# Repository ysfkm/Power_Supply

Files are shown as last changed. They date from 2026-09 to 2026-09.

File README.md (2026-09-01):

# Power Supply

## Summary
- Custom linear-regulator power supply boards providing multiple regulated rails from a raw input voltage.
- **v0.1:** 24V input board with four fixed regulators (15V, 12V, 5V, 3V3) plus two variable outputs via jumpers and a buck converter; four-layer 157.5mm x 100mm PCB.
- **v1.1:** Revised ±15V input board delivering +12V and -5V, entirely from linear regulators (12V now derived from 15V instead of 24V, plus a new -5V rail); same 4-layer 157.5mm x 100mm PCB footprint.

## v0.1

### Specs
- **Input:** +24V
- **Output:** +15V, +12V, +5V, +3V3, two variable voltage outputs
- **Description:** one output for each voltage value and two variable outputs via jumpers. Uses four regulators and one buck converter.
- **PCB:** 157.5mm x 100mm / 4 Layer

### 15V Voltage Regulator
- **Input:** 24V, GNDA
- **Output:** 15V, GNDA
- **Maximum Output Current:** 1A
- **Thermal Resistance:** 44.8°C/W

### 12V Voltage Regulator
- **Input:** 24V, GNDA
- **Output:** 12V, GNDA
- **Maximum Output Current:** 1A
- **Thermal Resistance:** 44.8°C/W

### 5V Voltage Regulator
- **Input:** 24V, GNDA
- **Output:** 5V, GNDA
- **Maximum Output Current:** 1.2A
- **9V Buck Converter Thermal Resistance:** 50°C/W
- **5V Linear Regulator Thermal Resistance:** 44.8°C/W

### 3V3 Voltage Regulator
- **Input:** 9V, GNDA
- **Output:** 3V3, GNDA
- **Maximum Output Current:** 5A
- **Thermal Resistance:** 44.8°C/W

### Design Process
- Thermal vias for each regulator for heat dissipation
- Buck converter routed to minimize loop area of interference
- Built four voltage regulators separately, then tested out ideas on how to put together a combined power supply board
- Settled on two variable outputs and four constant outputs

## v1.1

### Specs
- **Input:** +15V, -15V, GNDA
- **Output:** +12V, -5V, GNDA
- **Description:** three output ports for each voltage value. All regulated from linear regulators
- **PCB:** 157.5mm x 100mm / 4 Layer

### 12V Voltage Regulator
- **Input:** 15V, GNDA
- **Output:** 12V, GNDA
- **Maximum Output Current:** 1.5A
- **Thermal Resistance:** 19°C/W

### -5V Voltage Regulator
- **Input:** -15V, GNDA
- **Output:** -5V, GNDA
- **Maximum Output Current:** 1A
- **Thermal Resistance:** 65°C/W

### Design Changes
- Needed -5V supply so made a new version of the board with 12V and -5V
- 12V now regulated from 15V instead of 24V, so used a different regulator

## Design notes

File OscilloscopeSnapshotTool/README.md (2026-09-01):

# Power Supply Snapshot Tool

A small tool for grabbing a one-shot snapshot from the Rigol DS1104Z Plus
oscilloscope over LAN — for documenting the ripple/noise performance, its
frequency spectrum, and the actual output level of the power supply
board's outputs. Each run saves a screenshot and the underlying waveform
data for **three** passes — AC-coupled (ripple/noise), FFT (frequency
spectrum of that ripple), and DC-coupled (actual level) — together in
their own timestamped folder, so it's always obvious which files belong
together. There's also an optional **long capture** — a much longer
(1,000,000-point) raw trace and a full-resolution FFT computed from it —
you can tick on before clicking Take Snapshot; see
[Long trace capture](#long-trace-capture) below.

Waveform data is saved as compressed NumPy `.npz` files rather than CSV
(a PI's suggestion, since the long trace in particular is unwieldy as
text) — see [Reading the .npz files in Python](#reading-the-npz-files-in-python).

## What it does

Each time you click **Take Snapshot** (or run the command-line version),
the tool:

1. Connects to the oscilloscope over LAN.
2. **AC pass**: sets CH1 to AC coupling with a fixed **10mV/div scale,
   0V offset, and 100ns/div timebase** (so ripple is clearly visible
   regardless of what was set before), turns the "Measure All" statistics
   table **off** (to give the waveform as much of the plot as possible),
   freezes the trace, and saves the waveform (`.npz`) and screenshot (PNG)
   as `..._AC.npz` / `..._AC.png`.
3. **FFT pass**: uses the scope's built-in MATH FFT feature on that same
   AC-coupled signal, first switching to a **10µs/div timebase** (the
   FFT's frequency range/resolution comes from this, not a separate
   setting - a slower timebase than AC's gives better low-frequency
   resolution for typical switching-noise frequencies) - Hanning window,
   dB units, full-screen grid, CH1's time-domain trace still shown
   alongside it, auto-scaled via `:MATH:RESet` after giving the scope a
   moment to compute a real result first - to get the frequency spectrum,
   "Measure All" also off. It then repositions **0Hz to the left edge**
   and **0dB to the vertical center** of the spectrum plot (see "FFT axis
   positioning" below) and saves `..._FFT.npz` (frequency_hz,
   magnitude_dB) / `..._FFT.png`.
4. **DC pass**: switches CH1 to DC coupling, a fixed **1ms/div timebase**
   (this pass just reads a level, so the exact timebase barely matters -
   picked a fixed, moderate value rather than depending on whatever the
   scope was last left at), and a scale/offset that frames the actual
   output level — based on the **expected DC voltage** you type in (see
   below), or a safe wide default if left blank — turns "Measure All"
   **on** (useful alongside the level readout here), then freezes the
   trace and saves `..._DC.npz` / `..._DC.png`.
5. Measures the actual DC level and reports how it compares to what you
   expected (higher/lower, and by how much).
6. Resumes live acquisition on the scope so you can keep watching between
   captures — you never need to touch Run/Stop yourself. The scope is left
   showing the **DC pass's settings** (not reverted back to AC) and
   actively running, not frozen.

The AC pass uses **fixed** scale/offset/timebase every run (rather than
trying to preserve whatever was manually set before) — this is deliberate,
since letting it drift from run to run made AC data look inconsistent
between captures for no real circuit reason. If 10mV/div or 100ns/div
isn't right for what you're seeing, change `AC_FIXED_SCALE` /
`AC_FIXED_TIMEBASE` near the top of `capture.py`. The FFT window function,
units, and timebase are similarly fixed via `FFT_WINDOW` / `FFT_UNIT` /
`FFT_FIXED_TIMEBASE`, and the DC pass's timebase via `DC_FIXED_TIMEBASE`,
in the same file.

## Expected DC voltage field

This is optional but recommended. Typing in the rail's nominal voltage
(e.g. `12`, `5`, `3.3`) before capturing:
- Sets a scale/offset that safely frames and centers that value on screen
  before switching to DC coupling.
- Gets compared against the actual measured level afterward, so you can
  immediately see if the rail is reading higher or lower than expected and
  by how much.

If left blank, the DC pass falls back to a generously wide scale so
nothing clips, at the cost of less precise framing and no comparison.

## 1. One-time setup (per computer)

If you don't already have Python:
1. Download Python 3.11+ from https://www.python.org/downloads/
2. During install, check **"Add python.exe to PATH"**.
3. Verify from a terminal: `python --version`

If you already have another Python install (e.g. from MSYS2, Anaconda, or a
Microsoft Store install) and `python --version` doesn't show the one you
just installed, use the **`py`** launcher command instead of `python` for
everything below (`py --version`, `py -m pip install ...`, `py main.py`).

Then install the dependencies (only needs doing once per computer):
```
cd "G:\Shared drives\IAMSYbElectronics\Projects\Power_Supply\OscilloscopeSnapshotTool"
pip install -r requirements.txt
```

## 2. Find the oscilloscope's IP address

On the DS1104Z Plus:
1. Press **Utility** on the front panel.
2. Go to **IO Setting** (or **System → IO**, depending on firmware).
3. Select **LAN** and confirm it shows a real IP address (not `0.0.0.0`).

Make sure the scope and your computer are on the same network.

## 3. Wiring

Probe the power supply output you're testing with the scope's **CH1**
input. The tool always captures CH1 — if you need to probe a different
channel, change the `CHANNEL` constant near the top of `capture.py`.

## 4. Taking a snapshot

There are two ways to run this: the **GUI** (recommended, no typing
commands each time) or the **command line** script.

### GUI

1. Run:
   ```
   python main.py
   ```
   The window has a fixed size, but its content scrolls (mouse wheel, or
   the scrollbar on the right) if it doesn't fully fit - e.g. on a
   smaller screen or with larger system font/DPI scaling.
2. Enter the scope's IP address and click **Test Connection** to confirm
   it's reachable (you should see its `*IDN?` response pop up).
3. Optionally, type in the rail's **expected DC voltage**.
4. Optionally, tick **Also do a long capture** if you want the much
   longer raw trace + FFT this run too — see
   [Long trace capture](#long-trace-capture) below for what that gives
   you and when you'd want it.
5. Click **Take Snapshot**. The progress bars (AC, FFT, DC, and Long
   capture if ticked) show which pass is currently running, then switch
   to "Done" once each finishes. The scope freezes briefly during each
   pass and resumes automatically afterward. If the long capture checkbox
   was left unticked, its progress bar just stays "Idle" the whole time —
   that pass is skipped entirely.
6. Once everything shows "Done", the label below shows the folder it
   saved to, plus the measured DC level (and how it compares to what you
   typed in, if anything).

Click **Take Snapshot** again for each new output/condition you want to
document — every click gets its own timestamped folder, so nothing gets
overwritten.

### Command line (alternative)

```
python capture.py <scope_ip>
```
It'll then prompt for the expected DC voltage and whether to include a
long capture too (press Enter to skip either). Same behavior as the
GUI's Take Snapshot button, just without the window — useful if you want
to script/automate captures yourself.

Either way, output lands in `Snapshots\snapshot_<timestamp>\`, containing:
- `snapshot_<timestamp>_AC.npz` / `_AC.png` — ripple/noise
- `snapshot_<timestamp>_FFT.npz` / `_FFT.png` — frequency spectrum of the ripple
- `snapshot_<timestamp>_DC.npz` / `_DC.png` — actual output level
- `longcapture_<timestamp>\` — only if the long capture was included (see
  below)

All files share the same timestamp, so they're always easy to match up.

## Long trace capture

An optional capture (a PI's suggestion) for cases where the regular
~1200-point AC/FFT passes above aren't enough — it reads back the scope's
**full internal acquisition memory** for CH1 (1,000,000 points, same
fixed AC-coupled scale/offset/timebase as the regular AC pass — this is
meant to be the same ripple signal, just with far more of the actual
acquisition read back instead of only what fits on screen) and computes a
**full-resolution FFT from it in Python** (via numpy, not the scope's own
on-screen MATH FFT — the long record's whole benefit is finer frequency
resolution than a screen-limited display can show).

- **GUI**: tick **Also do a long capture** before clicking **Take
  Snapshot** — it then runs as a fourth pass in the same run, right after
  DC. Leave it unticked for a routine snapshot without the extra time
  this pass adds (transferring a million points over LAN, even in
  binary, isn't instant).
- **Reconnects fresh right before the long capture itself** (a short
  pause, then a brand new connection), rather than reusing the same
  connection the AC/FFT/DC passes just used. Real-hardware testing found
  the long capture's big chunked transfer noticeably more likely to fail
  partway (`VI_ERROR_IO`) on a connection that had already been through
  those three passes' own substantial command traffic, but consistently
  succeeded cleanly on a fresh connection - this gives it that same
  advantage without needing to redo the entire AC/FFT/DC sequence just to
  get one.
- **Command line**: answer "y" to the "Include long capture too?" prompt
  when running `python capture.py <scope_ip>`.
- **Isolated in its own subfolder**, `longcapture_<timestamp>\` (same
  timestamp as the rest of the run), nested inside the main
  `snapshot_<timestamp>\` folder rather than mixed in loose alongside the
  AC/FFT/DC files:
  - `snapshot_<timestamp>_LONG_AC.npz` (time_s, CH1_volts)
  - `snapshot_<timestamp>_LONG_FFT.npz` (frequency_hz, magnitude_V, magnitude_dB)
  - `snapshot_<timestamp>_LONG.png` - a quick-look plot (time-domain trace
    on top, FFT spectrum on bottom) generated directly from the `.npz`
    data with matplotlib. There's no on-scope screenshot for this data
    (nothing meaningful to show on the scope's own screen for a record
    this size - it can't display all 1,000,000 points or compute a
    matching on-screen FFT), so this PNG is the only visual reference for
    a long capture run.
- **Standalone alternative**: if you want *just* the long capture without
  running the full AC/FFT/DC sequence, use `python capture.py <scope_ip>
  --long` instead - this saves into its own separate top-level
  `Snapshots\longcapture_<timestamp>\` folder (not nested under a regular
  snapshot, since there isn't one in this case).
- The actual sample rate/memory depth the scope accepted, and the real
  time span those 1,000,000 points cover, are printed to the console
  (`[Long capture] ...`) each run — worth checking if the frequency range
  in the FFT doesn't look like what you expected.
- The chunked binary transfer itself (4 chunks of 250,000 points each)
  logs each chunk as it completes (`[Long capture read] chunk 1/4 ...`) -
  added after a real-hardware run went silent partway through this
  transfer with no indication of which chunk (or whether the transfer
  itself) had failed. If a chunk fails, the log now says exactly which
  one and what VISA error it hit, before the whole capture retries.
- If the long capture fails partway through, its `longcapture_<timestamp>`
  subfolder is never created at all (rather than being left behind
  empty) - the folder only appears once the raw capture and FFT have
  both actually succeeded and there's real data to save.
- `LONG_TRACE_POINTS` (target point count) and `LONG_TRACE_MDEPTH` (the
  actual memory depth requested from the scope — a fixed list of values on
  this hardware, not an arbitrary number) are both in `capture.py` if you
  need to change them.

## Reading the .npz files in Python

Every waveform (short or long trace) is saved as a compressed NumPy
`.npz`, not CSV — a PI's suggestion, since the long trace especially would
be an unwieldy multi-megabyte text file otherwise. Load one like this:

```python
import numpy as np

data = np.load("snapshot_20260810_120000_AC.npz")
print(list(data.keys()))       # e.g. ['time_s', 'CH1_volts']
times, volts = data["time_s"], data["CH1_volts"]
```

Each file's array names describe what they hold (`time_s`/`CH1_volts` for
AC/DC/long-trace captures, `frequency_hz`/`magnitude_dB` for the scope's
FFT pass, `frequency_hz`/`magnitude_V`/`magnitude_dB` for the long-trace
FFT) — no separate header or documentation needed to know what's inside.

## Notes

- The short-pass `.npz` files capture whatever is **currently on the
  screen** (~1200 points, the same "NORMal" waveform mode the scope itself
  displays) — not the scope's full internal memory depth. This matches
  what you see in the matching screenshot. (For the full internal memory
  depth, see [Long trace capture](#long-trace-capture) above.)
- **FFT is computed by the scope itself** (its built-in MATH FFT feature),
  not by this tool — frequency resolution and range depend on the current
  timebase/sample rate, same as if you'd set it up on the front panel.
  CH1's time-domain trace stays visible alongside the spectrum in the FFT
  screenshot — hiding CH1's display was tried, but real-hardware testing
  suggested the FFT stopped producing a result when its source channel
  wasn't visible, so that's kept on for now. "Measure All" statistics
  can't show anything FFT-specific either way, since the scope's
  measurement engine only supports the physical channels
  (CH1-CH4), never the MATH/FFT result.
- **FFT frequency axis**: on this scope, `:MATH:FFT:HCENter` sets whatever
  frequency sits at the *horizontal center* of the screen (it defaults to
  5MHz) — it does **not** default to putting 0Hz at the left edge, so
  without setting it explicitly, 0Hz could end up sitting well inside the
  plot with a dead, unused gap to its left (confusing to read, and exactly
  what earlier real captures showed). After `:MATH:RESet` auto-fits the
  frequency span (`:MATH:FFT:HSCale`) to the real sample rate, the code
  now repositions the center so **0Hz lands at the left edge** — using as
  much of the plot as possible for the actual spectrum, the same way you'd
  expect a real spectrum analyzer to lay it out. (If the display looks
  like there's no obvious dominant frequency, that's more likely a
  genuinely broadband/noisy signal, or the FFT span from the 10µs/div
  timebase not centering on the frequency you expected, than a display
  layout issue — the console output when running from the command line
  prints the actual HSCale/HCENter used for each run, useful for checking
  what frequency range was actually captured.) The vertical axis gets the
  same treatment: `:MATH:RESet` auto-fits the dB/div scale to the actual
  spectrum, then `:MATH:OFFSet` is explicitly set to 0 afterward, which
  *should* put 0dB at the exact vertical center the same way 0 offset
  centers a regular channel — **but a real capture showed the MATH
  zero-reference marker (the small arrow on the screen's left edge)
  sitting visibly below true center** despite the write going through
  with no error, so that convention doesn't seem to carry over to MATH
  the same way. Still open — the console now also prints the actual
  read-back `:MATH:OFFSet?` value (`[FFT vertical] ...`) so the next real
  run can confirm whether the write itself is taking hold before trying a
  numeric correction.
- The console output (visible when running `python capture.py` directly,
  or in whatever terminal launched the GUI) also prints any errors the
  scope's own `:SYSTem:ERRor?` queue reports — checked after the AC pass,
  the FFT setup, and the DC pass — if something like "Invalid Input!" ever
  shows up on the scope's screen again, check there first for the exact
  rejected command instead of guessing. Real-hardware runs came back
  completely clean across the AC/FFT checkpoints, with "Invalid Input!"
  still showing on screen — meaning it isn't coming from any SCPI command
  in this sequence. Worth checking whether it's a stale message left over
  from something else entirely, or a front-panel/touchscreen glitch from
  nearby EMI, given this runs right next to a power supply board under
  test.
- **This diagnostic caused its own bug once**: the DC pass's
  `:SYSTem:ERRor?` check occasionally timed out outright on real
  hardware. Since that raised the same VisaIOError the LAN reconnect
  logic watches for, `run_capture()`'s retry wrapper caught it and
  restarted the *entire* AC→FFT→DC sequence from scratch — three
  timeouts in a row looked like the tool "got stuck in a loop", leaving
  three dead folders that each only got as far as AC+FFT. Fixed by having
  `_drain_scope_errors()` catch a timeout on its own query and just skip
  that check, instead of letting it take down the whole capture.
- **Fine vs. Coarse vertical scale**: the code now explicitly forces
  `:CHANnel:VERNier ON` (Fine mode) after every coupling switch, before
  setting any scale. Without this, whatever Fine/Coarse state the front
  panel was last manually left in would govern whether a requested scale
  actually got applied exactly - Coarse mode only allows the standard
  1-2-5 step sequence (1mV, 2mV, 5mV, 10mV, 20mV...) and silently snaps
  anything else to the nearest one. This barely matters for the AC pass
  (10mV/div is already a standard step) but matters a lot for the DC
  pass, since `choose_dc_scale()` computes an arbitrary value (e.g.
  1.2V/div for a 12V rail) that Coarse mode would otherwise quietly
  distort.
- **Trigger settings are now fixed too**: sweep mode `AUTO`, edge trigger
  on CH1, level 0V for the AC/FFT/long-trace passes and the expected DC
  voltage (or 0V if none given) for the DC pass. Previously trigger
  settings were never touched at all, meaning they depended entirely on
  whatever was last set manually. If the scope was left in `Normal` sweep
  mode with a level the current signal doesn't reliably cross, it just
  holds onto whatever it last successfully triggered on - possibly stale
  data from a completely different pass or coupling state - instead of
  acquiring anything fresh, which could look like "different results every
  time" between runs with no other explanation. `AUTO` sweep mode avoids
  this failure mode entirely by always producing a fresh acquisition on a
  timeout even without a clean edge. Console lines `[AC trigger]` /
  `[DC trigger]` confirm what was set on each run.
- **Cursors are forced off** (`:CURSor:MODE OFF`) as the very first thing
  every run does, before anything else - the small AX/AY/BX/BY/BX-AX
  readout box left over from manual front-panel use would otherwise sit
  on top of the plot in every screenshot.
- **DC framing internals**: the scope's max allowed vertical offset
  depends on the current scale — under 500mV/div it's only ±2V, but from
  500mV/div up it's ±100V. Since every rail on this board needs more than
  2V of offset to center, the DC scale is never allowed to go below
  500mV/div (`MIN_DC_SCALE_FOR_OFFSET_RANGE` in `capture.py`), even if a
  tighter zoom would otherwise look nicer for a small rail like 3.3V.
- If you get a connection error, double-check the IP address and that
  nothing (e.g. a firewall) is blocking the connection — same
  troubleshooting as the filter sweep tool in the `LPFilters_Elliptical`
  project. Repeated captures can occasionally hit a stale-connection error;
  the tool automatically retries a few times (with a 5-second pause
  between attempts) before giving up. A folder is only created once the
  connection actually succeeds, so a failed retry doesn't leave an empty
  folder behind.
- **`VI_ERROR_RSRC_NFOUND` after a long capture**: real-hardware testing
  found that reconnecting right after a run that included a long capture
  could fail outright with "resource not found" (not just a slow
  response) - the LAN interface seems to need more recovery time after a
  connection that stayed open much longer and moved far more data than
  the routine passes. The retry pause was increased from 1.5s to 5s to
  give it more room; if this still happens, waiting a bit longer before
  retrying manually, or power-cycling the scope's LAN interface (Utility →
  IO Setting), should clear it.

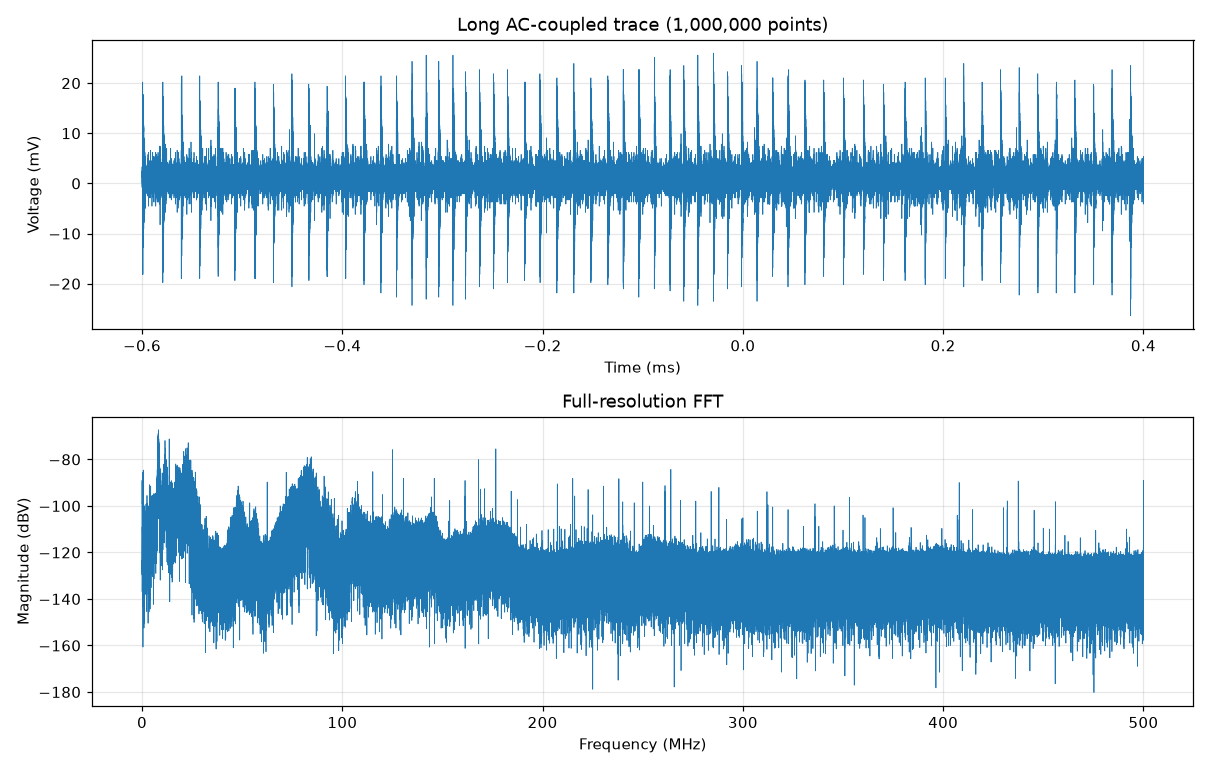
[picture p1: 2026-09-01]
OscilloscopeSnapshotTool/Snapshots/v0.1_+12V_20260813_135134/longcapture_20260813_135134/snapshot_20260813_135134_LONG.png

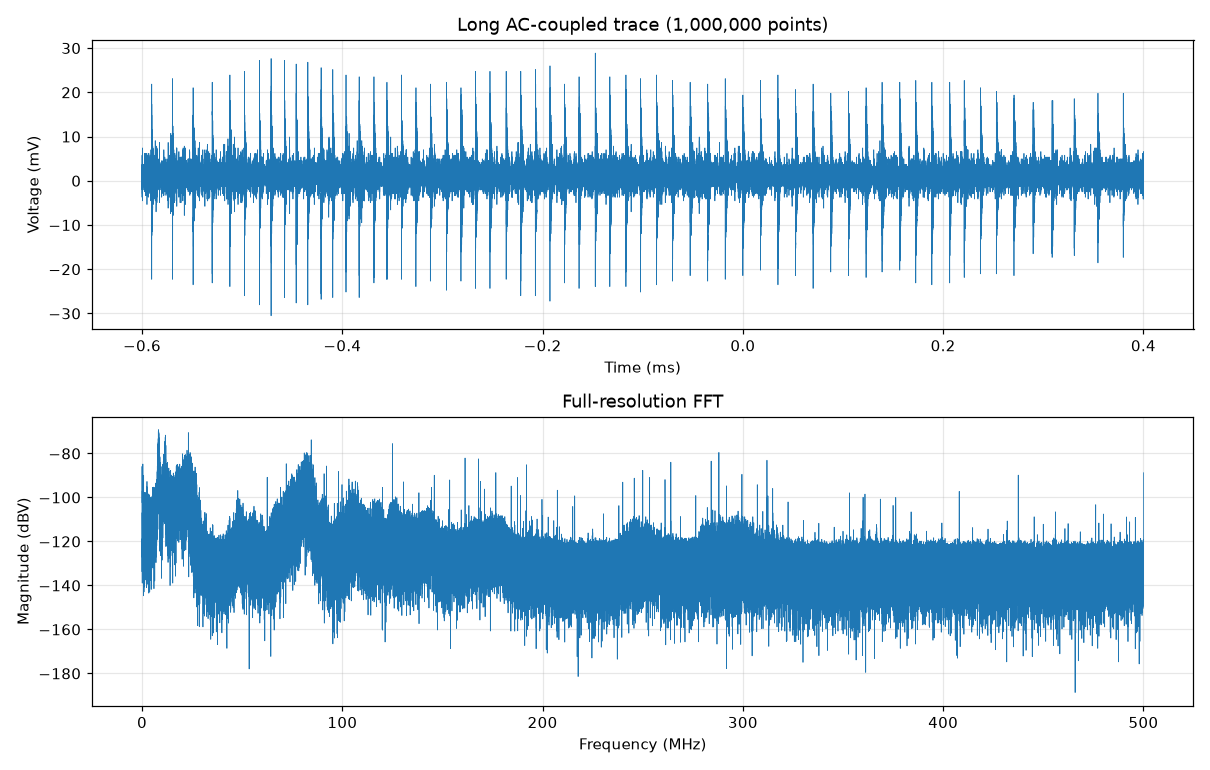
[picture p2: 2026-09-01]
OscilloscopeSnapshotTool/Snapshots/v0.1_+15V_20260813_135932/longcapture_20260813_135932/snapshot_20260813_135932_LONG.png

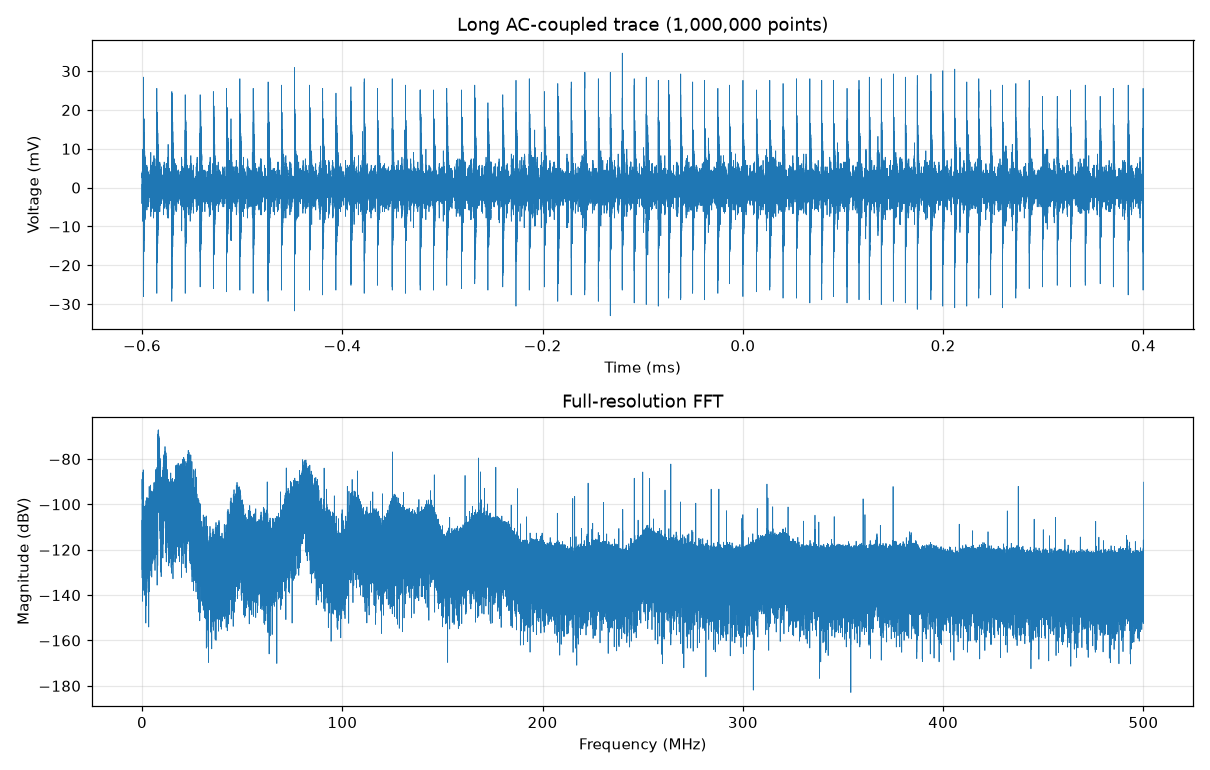
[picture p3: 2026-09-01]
OscilloscopeSnapshotTool/Snapshots/v0.1_+3V3_20260813_133453/longcapture_20260813_133453/snapshot_20260813_133453_LONG.png

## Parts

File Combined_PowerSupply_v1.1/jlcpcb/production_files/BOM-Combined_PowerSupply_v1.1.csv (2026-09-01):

Comment | Designator | Footprint | LCSC | Quantity
C131946-UA7812CKTTR | U4 | C131946-TO-263-3L_L10.0-W9.2-P2.54-TL | C131946 | 1
10uF, 50V | C13,C14,C17,C20 | C_1206_3216Metric | C13585 | 4
100nF, 50V | C12 | C_0603_1608Metric | C14663 | 1
1uF, 50V | C16 | C_0603_1608Metric | C15849 | 1
330nF, 50V | C11 | C_0603_1608Metric | C282682 | 1
C358376-79D05 | U5 | C358376-TO-252-2_L6.5-W6.1-P4.58-LS10.0-BR | C358376 | 1
C3697-WJ2EDGRC-5.08-02P-14-00A | CN1,CN11,CN3,CN5,CN7,CN9 | C3697-CONN-TH_2P-P5.08_WJ2EDGRC-5.08-2P | C3697 | 6
C5173368-9001-14641C00A | J1 | C5173368-CONN-TH_WINGTAT_9001-14641C00A | C5173368 | 1
2.2uF, 25V | C15 | C_0603_1608Metric | C57895 | 1
C71370-WJ2EDGK-5.08-02P-14-00A | CN10,CN12,CN2,CN4,CN6,CN8 | C71370-FL_001 | C71370 | 6

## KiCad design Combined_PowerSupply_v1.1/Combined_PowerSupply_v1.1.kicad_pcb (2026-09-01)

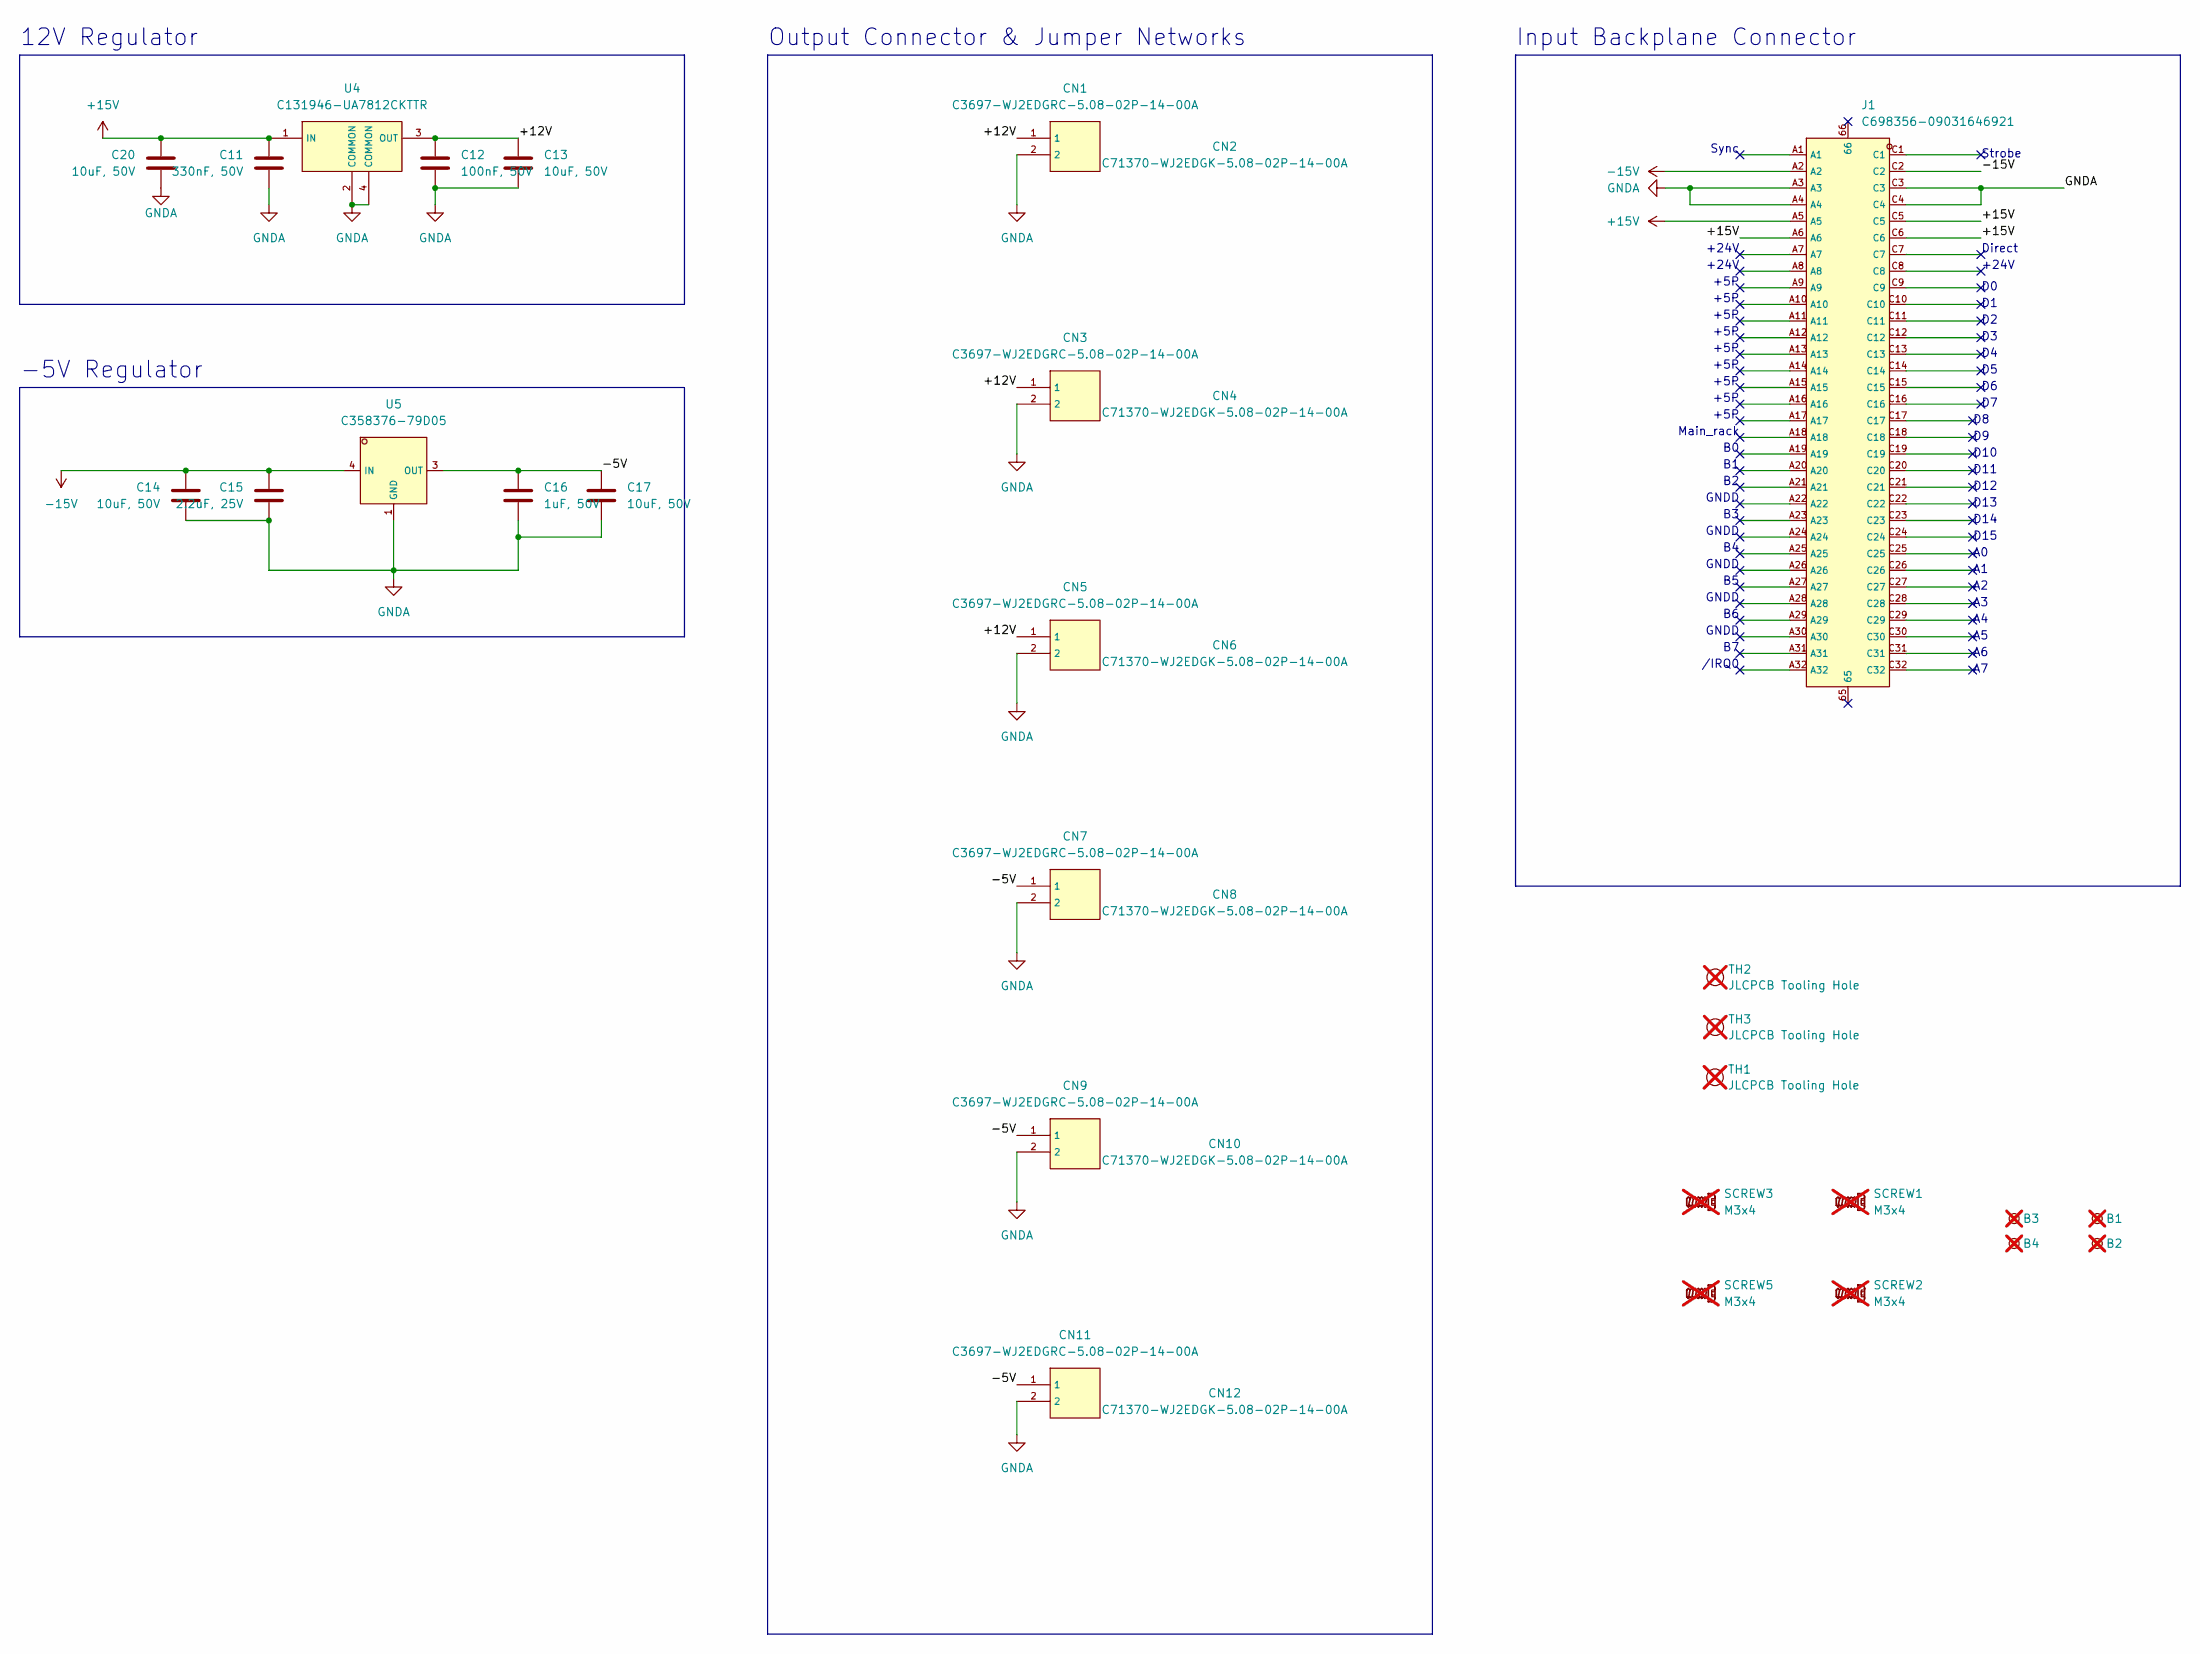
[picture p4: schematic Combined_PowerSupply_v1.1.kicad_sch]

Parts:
B1, B2, B3, B4: M3 Mounting Hole; MountingHole_3.2mm_M3_DIN965_Pad; not fitted
C11: 330nF, 50V; C_0603_1608Metric; LCSC C282682
C12: 100nF, 50V; C_0603_1608Metric; LCSC C14663
C13, C14, C17, C20: 10uF, 50V; C_1206_3216Metric; LCSC C13585
C15: 2.2uF, 25V; C_0603_1608Metric; LCSC C57895
C16: 1uF, 50V; C_0603_1608Metric; LCSC C15849
CN1, CN3, CN5, CN7, CN9, CN11: C3697-WJ2EDGRC-5.08-02P-14-00A; C3697-CONN-TH_2P-P5.08_WJ2EDGRC-5.08-2P; LCSC C3697
CN2, CN4, CN6, CN8, CN10, CN12: C71370-WJ2EDGK-5.08-02P-14-00A; C71370-FL_001; LCSC C71370
J1: C698356-09031646921; C698356-CONN-TH_64P-P2.54_HARTING_09031646921; LCSC C698356
SCREW1, SCREW2, SCREW3, SCREW5: M3x4; SCREW_M3; not fitted
TH1, TH2, TH3: JLCPCB Tooling Hole; ToolingHoles; not fitted
U4: C131946-UA7812CKTTR; C131946-TO-263-3L_L10.0-W9.2-P2.54-TL; LCSC C131946
U5: C358376-79D05; C358376-TO-252-2_L6.5-W6.1-P4.58-LS10.0-BR; LCSC C358376

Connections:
+15V: C11.1, C20.1, J1.A5, J1.A6, J1.C5, J1.C6, U4.1 (IN)
-15V: C14.1, C15.1, J1.A2, J1.C2, U5.4 (IN)
/+12V: C12.1, C13.1, CN1.1, CN3.1, CN5.1, U4.3 (OUT)
/-5V: C16.1, C17.1, CN7.1, CN9.1, CN11.1, U5.3 (OUT)
GNDA: C11.2, C12.2, C13.2, C14.2, C15.2, C16.2, C17.2, C20.2, CN1.2, CN3.2, CN5.2, CN7.2, CN9.2, CN11.2, J1.A3, J1.A4, J1.C3, J1.C4, U4.2 (COMMON), U4.4 (COMMON), U5.1 (GND)

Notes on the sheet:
+24V
+5P
Main_rack
D15
Strobe
GNDD
D13
-5V Regulator
D14
/IRQ0
Input Backplane Connector
Direct
Sync
D10
12V Regulator
Output Connector & Jumper Networks
D12
D11

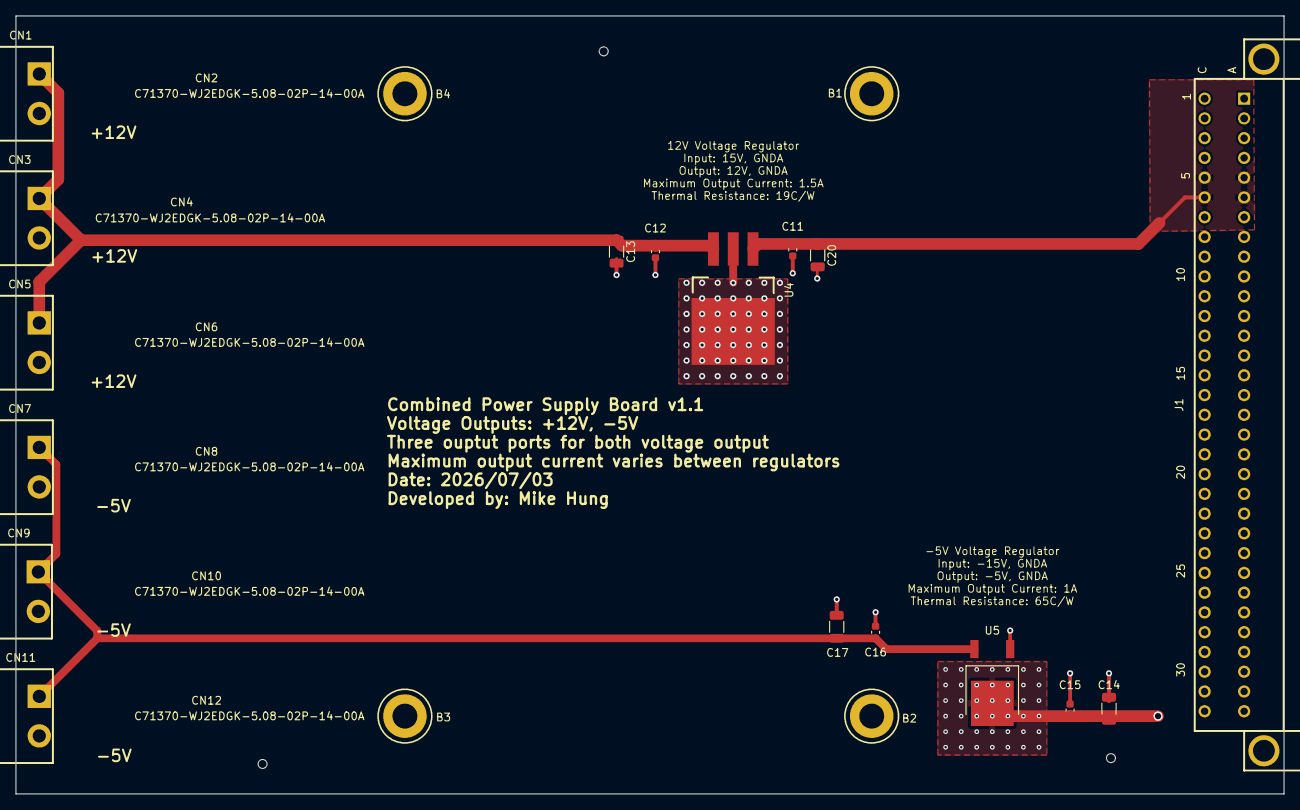
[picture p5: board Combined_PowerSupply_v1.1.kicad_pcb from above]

Board: 4 copper layers, 163.0 x 100.0 mm, 34 parts (0 on the bottom side), 5 nets.

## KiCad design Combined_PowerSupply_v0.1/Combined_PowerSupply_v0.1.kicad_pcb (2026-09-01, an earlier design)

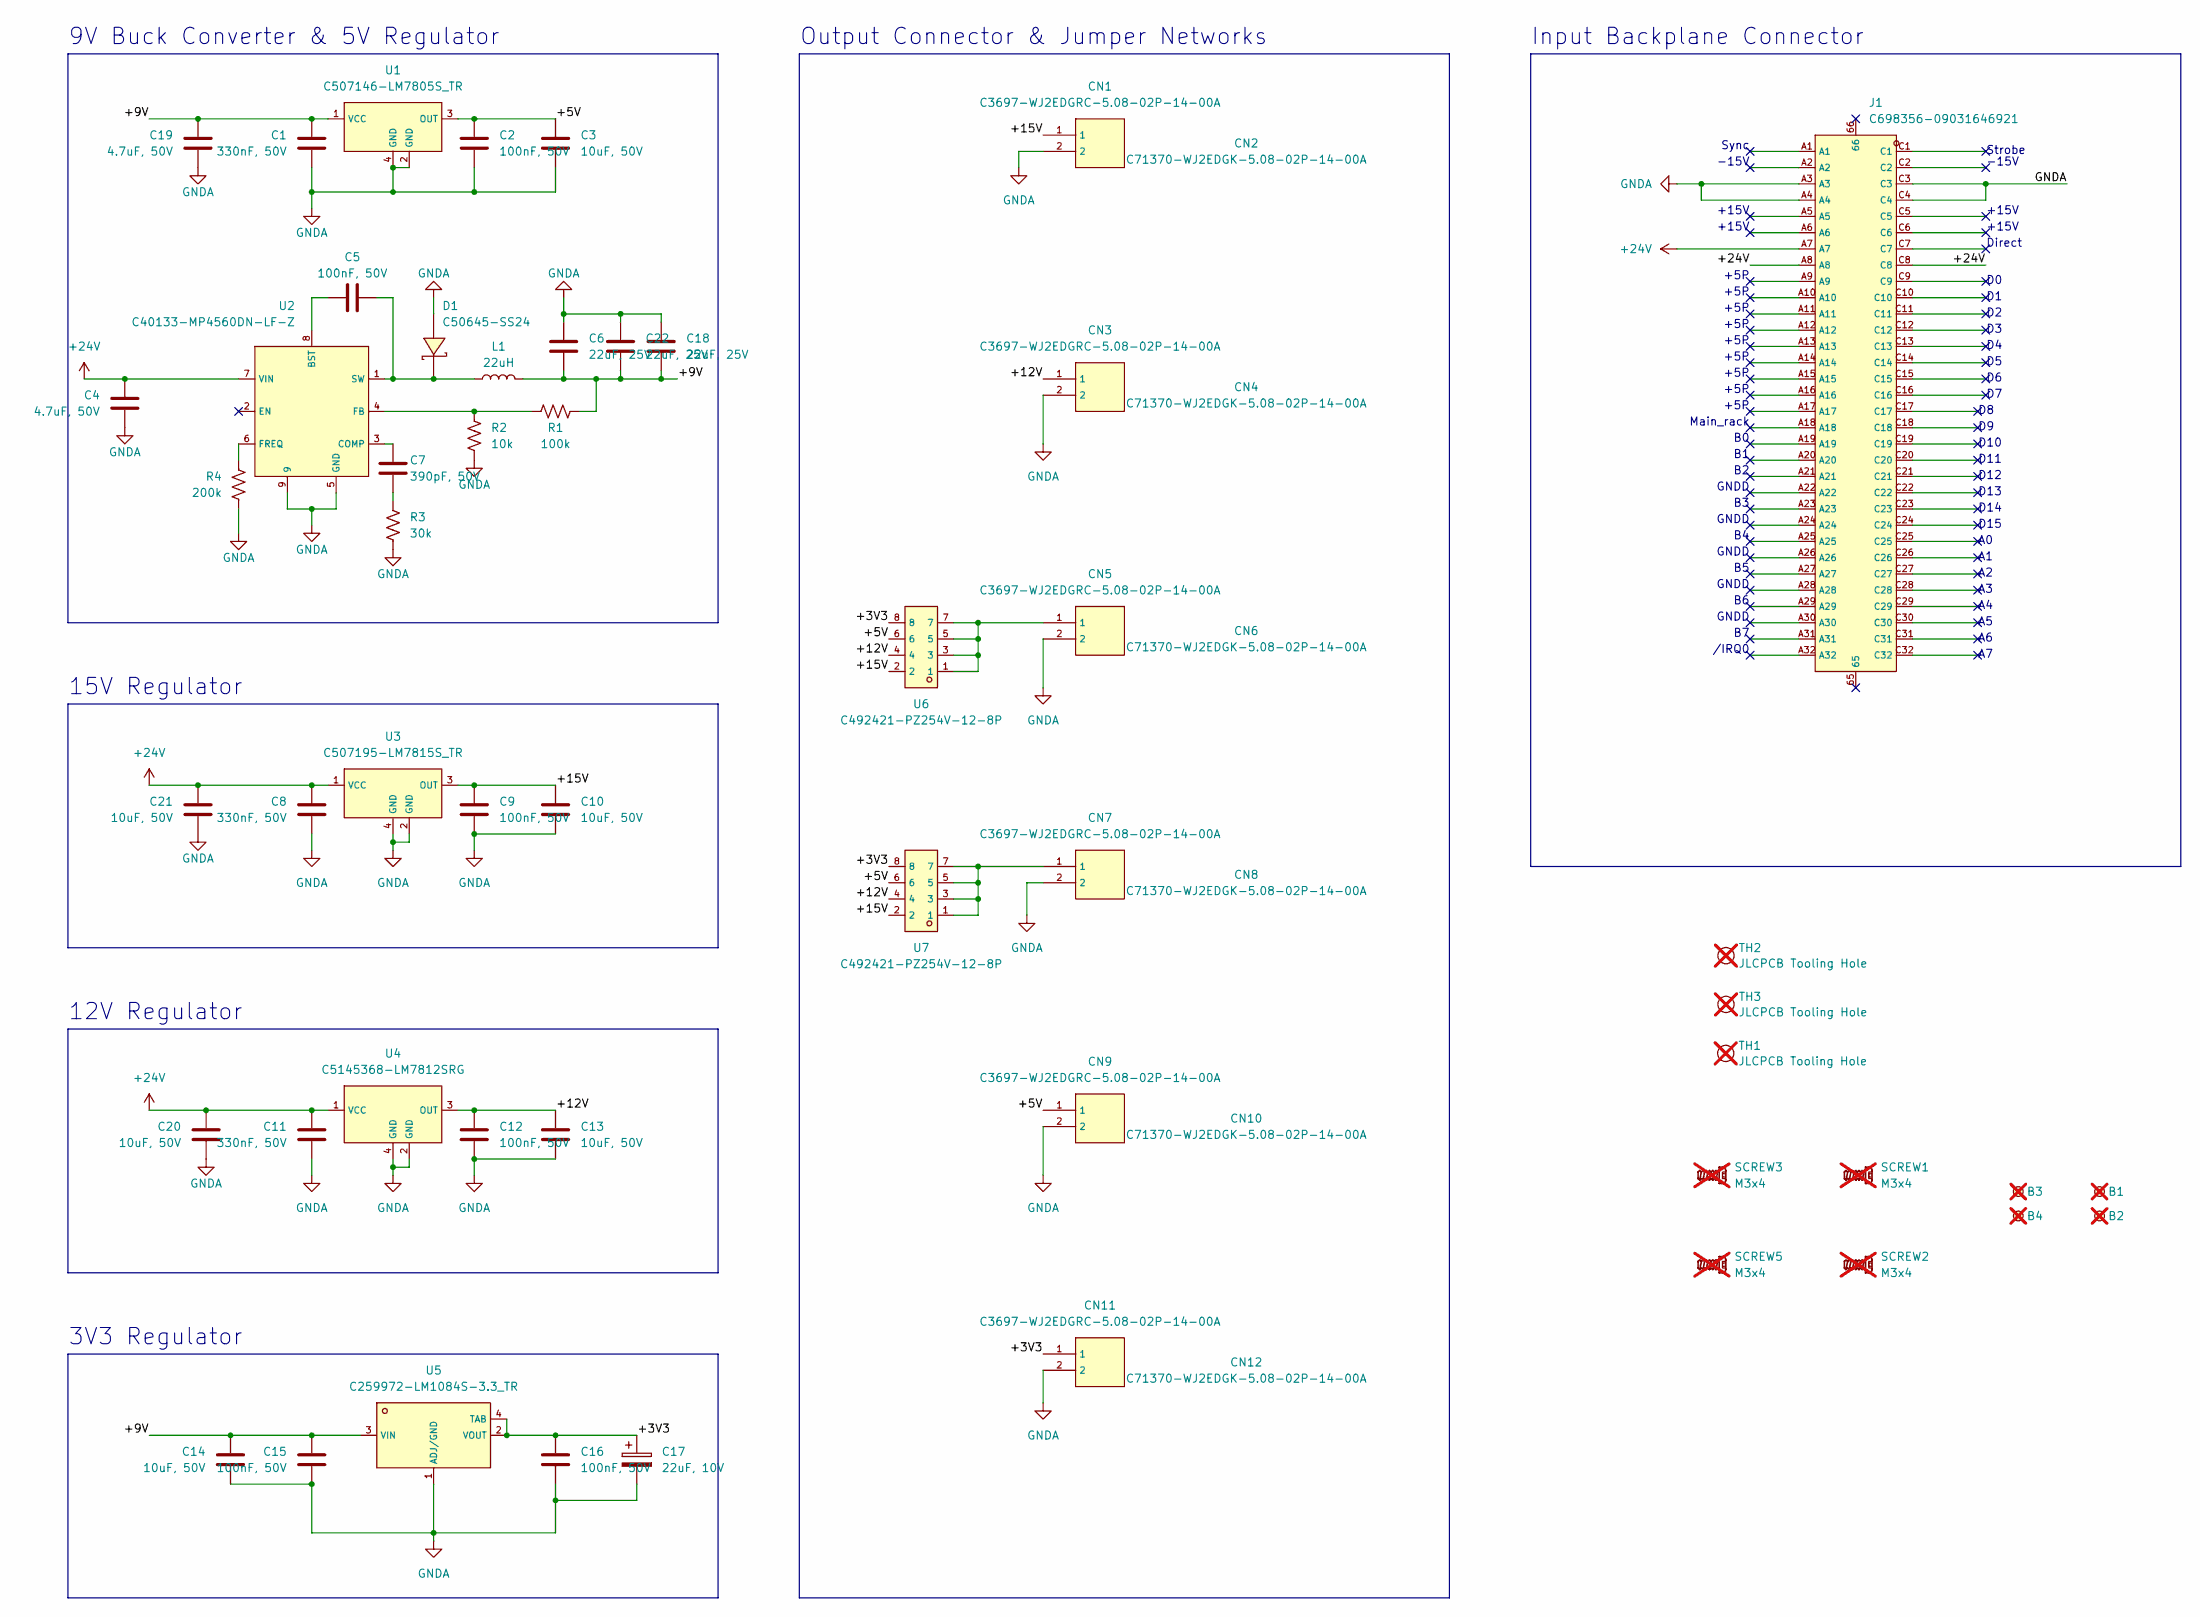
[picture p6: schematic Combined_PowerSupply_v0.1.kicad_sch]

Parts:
B1, B2, B3, B4: M3 Mounting Hole; MountingHole_3.2mm_M3_DIN965_Pad; not fitted
C1, C8, C11: 330nF, 50V; C_0603_1608Metric; LCSC C282682
C2, C5, C9, C12, C15, C16: 100nF, 50V; C_0603_1608Metric; LCSC C14663
C3, C10, C13, C14, C20, C21: 10uF, 50V; C_1206_3216Metric; LCSC C13585
C4, C19: 4.7uF, 50V; C_0805_2012Metric; LCSC C437557
C6, C18, C22: 22uF, 25V; C_1206_3216Metric; LCSC C12891
C7: 390pF, 50V; C_0402_1005Metric; LCSC C76967
C17: 22uF, 10V; C11366-CASE-A_3216; LCSC C11366
CN1, CN3, CN5, CN7, CN9, CN11: C3697-WJ2EDGRC-5.08-02P-14-00A; C3697-CONN-TH_2P-P5.08_WJ2EDGRC-5.08-2P; LCSC C3697
CN2, CN4, CN6, CN8, CN10, CN12: C71370-WJ2EDGK-5.08-02P-14-00A; C71370-FL_001; LCSC C71370
D1: C50645-SS24; C50645-SMA_L4.3-W2.6-LS5.2-RD; LCSC C50645
J1: C698356-09031646921; C698356-CONN-TH_64P-P2.54_HARTING_09031646921; LCSC C698356
L1: 22uH; C475917-IND-SMD_L10.0-W10.0-LS11.0; LCSC C475917
R1: 100k; R_0402_1005Metric; LCSC C25741
R2: 10k; R_0402_1005Metric; LCSC C25744
R3: 30k; R_0603_1608Metric; LCSC C22984
R4: 200k; R_0402_1005Metric; LCSC C25764
SCREW1, SCREW2, SCREW3, SCREW5: M3x4; SCREW_M3; not fitted
TH1, TH2, TH3: JLCPCB Tooling Hole; ToolingHoles; not fitted
U1: C507146-LM7805S_TR; C507146-TO-263-3_L8.6-W10.2-P2.54-LS14.4-BR; LCSC C507146
U2: C40133-MP4560DN-LF-Z; C40133-SOIC-8_L4.9-W3.9-P1.27-LS6.0-BL-EP3.1-1; LCSC C40133
U3: C507195-LM7815S_TR; C507195-TO-263-3_L8.6-W10.2-P2.54-LS14.4-BR; LCSC C507195
U4: C5145368-LM7812SRG; C5145368-TO-263-3_L8.6-W10.2-P2.54-LS14.4-BR; LCSC C5145368
U5: C259972-LM1084S-3.3_TR; C259972-TO-263-3_L8.6-W10.2-P2.54-LS14.4-TL; LCSC C259972
U6, U7: C492421-PZ254V-12-8P; C492421-HDR-TH_8P-P2.54-V-M-R2-C4-S2.54; LCSC C492421

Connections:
+24V: C4.1, C8.1, C11.1, C20.1, C21.1, J1.A7, J1.A8, J1.C8, U2.7 (VIN), U3.1 (VCC), U4.1 (VCC)
/+3V3: C16.1, C17.1, CN11.1, U5.2 (VOUT), U5.4 (TAB), U6.8, U7.8
/+5V: C2.1, C3.1, CN9.1, U1.3 (OUT), U6.6, U7.6
/+9V: C1.1, C6.2, C14.1, C15.1, C18.2, C19.1, C22.2, L1.2, R1.2, U1.1 (VCC), U5.3 (VIN)
/+12V: C12.1, C13.1, CN3.1, U4.3 (OUT), U6.4, U7.4
/+15V: C9.1, C10.1, CN1.1, U3.3 (OUT), U6.2, U7.2
GNDA: C1.2, C2.2, C3.2, C4.2, C6.1, C8.2, C9.2, C10.2, C11.2, C12.2, C13.2, C14.2, C15.2, C16.2, C17.2, C18.1, C19.2, C20.2, C21.2, C22.1, CN1.2, CN3.2, CN5.2, CN7.2, CN9.2, CN11.2, D1.2 (A), J1.A3, J1.A4, J1.C3, J1.C4, R2.2, R3.2, R4.2, U1.2 (GND), U1.4 (GND), U2.5 (GND), U2.9, U3.2 (GND), U3.4 (GND), U4.2 (GND), U4.4 (GND), U5.1 (ADJ/GND)
unnamed: C7.1, R3.1
unnamed: CN5.1, U6.1, U6.3, U6.5, U6.7
unnamed: CN7.1, U7.1, U7.3, U7.5, U7.7
unnamed: C5.2, D1.1 (K), L1.1, U2.1 (SW)
unnamed: C5.1, U2.8 (BST)
unnamed: C7.2, U2.3 (COMP)
unnamed: R1.1, R2.1, U2.4 (FB)
unnamed: R4.1, U2.6 (FREQ)

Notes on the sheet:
+5P
Main_rack
D15
Strobe
GNDD
D13
15V Regulator
+15V
3V3 Regulator
D14
/IRQ0
-15V
Input Backplane Connector
Direct
Sync
D10
12V Regulator
9V Buck Converter & 5V Regulator
Output Connector & Jumper Networks
D12
D11

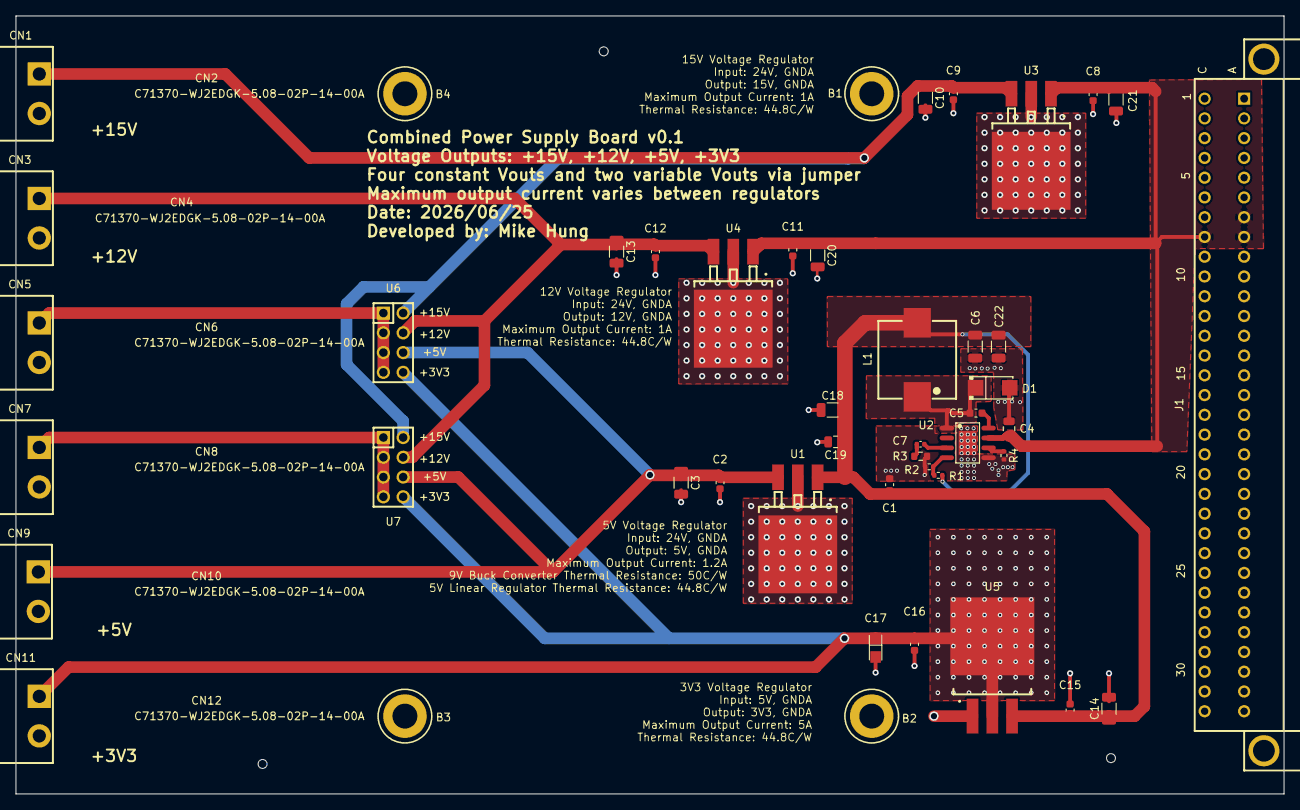
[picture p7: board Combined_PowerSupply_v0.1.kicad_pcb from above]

Board: 4 copper layers, 163.0 x 100.0 mm, 59 parts (0 on the bottom side), 15 nets.

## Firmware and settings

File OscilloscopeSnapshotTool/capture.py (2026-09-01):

"""One-shot capture tool for the Rigol DS1104Z Plus, over LAN.

Grabs an AC-coupled snapshot (ripple/noise), an FFT of that same ripple
(frequency spectrum), and a DC-coupled snapshot (actual output level) of
one channel - each as a screenshot (PNG) + waveform data (CSV), saved
together in their own timestamped folder under Snapshots/ so it's always
obvious which files belong together.

The AC pass uses a fixed scale/offset every run. The FFT pass uses the
scope's own built-in MATH FFT feature on the same AC-coupled signal. The DC
pass computes scale and offset automatically from a quick measurement of
the actual DC level, since that varies a lot between the different rails
this board outputs (3.3V, 5V, 12V, 15V, ...) and would otherwise need to be
re-tuned by hand every time.
"""

import math
import os
import sys
import time
from datetime import datetime

import numpy as np
import pyvisa

CHANNEL = 1  # which scope channel is probing the power supply output

# Rigol scopes return a sentinel value around 9.9E37 for an invalid
# measurement (e.g. not enough valid signal to compute it).
_INVALID_MEASUREMENT_THRESHOLD = 1e30

MIN_CHANNEL_SCALE = 0.001
MAX_CHANNEL_SCALE = 10

# Fixed AC-coupled viewing setup, used every run instead of trying to
# preserve/restore whatever was manually set before - simpler and more
# consistent between runs. Adjust here if 10mV/div isn't the right default
# for your ripple levels.
AC_FIXED_SCALE = 0.01
AC_FIXED_OFFSET = 0
# The scope only supports timebase values in a standard 1-2-5 step
# sequence (...50ns, 100ns, 200ns, 500ns, 1us...). Confirmed on real
# hardware that requesting a non-standard value (250ns) gets rounded UP to
# the next valid step (500ns), not to the nearest one - so 100ns is set
# directly here as an exact valid step, avoiding any rounding ambiguity.
AC_FIXED_TIMEBASE = 100e-9

# DC pass just needs to read a level, not characterize fast transients, so
# the exact timebase barely matters here - a moderate, fixed value just to
# avoid depending on whatever the scope was last left at.
DC_FIXED_TIMEBASE = 1e-3  # 1ms/div

# FFT is computed on the AC-coupled signal (the ripple/noise), using the
# scope's own built-in MATH FFT feature. HANNing is the standard
# general-purpose window for this kind of noise/ripple analysis - better
# balance of frequency resolution vs. amplitude accuracy than the scope's
# own default (Rectangle, more suited to one-shot transients). DB gives a
# log scale, which reads better than VRMS when multiple harmonics span a
# wide dynamic range.
FFT_WINDOW = "HANNing"
FFT_UNIT = "DB"

# The FFT's frequency range/resolution comes from the underlying time-
# domain timebase, NOT a separate setting - reusing AC's fast 500ns/div
# would push the Nyquist range into the 100s of MHz, squeezing whatever
# switching-frequency content you actually care about (likely under a few
# MHz) into a tiny sliver of the spectrum. This slower value trades some
# max frequency for better low-frequency resolution - a starting point,
# likely needs tuning once you see real spectra.
FFT_FIXED_TIMEBASE = 10e-6  # 10us/div

# ---- Long-trace capture (separate, on-demand - not part of the regular
# AC/FFT/DC snapshot sequence) -------------------------------------------
# Reads back the scope's full internal acquisition memory for CH1 (using
# the same fixed AC-coupled view as the regular AC pass) instead of just
# the ~1200 on-screen points, for a much longer/finer-resolution record -
# and computes an independent, full-resolution FFT from it in Python.
LONG_TRACE_POINTS = 1_000_000
# Confirmed against the real programming manual: with one channel enabled,
# :ACQuire:MDEPth only accepts {AUTO|12000|120000|1200000|12000000|
# 24000000} - not an arbitrary integer - so 1,000,000 itself isn't valid.
# This is the next step up; only the first LONG_TRACE_POINTS of it get
# read back and saved, so the saved trace is still exactly 1,000,000
# points.
LONG_TRACE_MDEPTH = 1_200_000
# Max points per single :WAVeform:DATA? query in RAW/BYTE mode - matches
# the chunk size used by the well-tested pklaus/ds1054z open-source driver
# for this same scope family.
_RAW_READ_CHUNK = 250_000
# Pause before reconnecting fresh specifically for the long capture (see
# run_capture()'s bundled long-capture step) - gives the scope's LAN
# interface time to release the AC/FFT/DC passes' connection before a new
# one takes its place, same reasoning as the outer retry delay.
_LONG_CAPTURE_RECONNECT_DELAY_S = 5.0


def _resource_string(ip_address):
    return f"TCPIP0::{ip_address}::INSTR"


def _strip_tmc_header(raw_bytes):
    """Strips the IEEE-488.2 TMC block header ('#<n><n digits of length>')
    from a raw SCPI binary-block response, returning just the data bytes.
    """
    if not raw_bytes.startswith(b"#"):
        return raw_bytes
    digit_count = int(raw_bytes[1:2])
    header_len = 2 + digit_count
    data_len = int(raw_bytes[2:header_len])
    return raw_bytes[header_len:header_len + data_len]


def _parse_measurement(raw_value):
    value = float(raw_value)
    if math.isnan(value) or abs(value) > _INVALID_MEASUREMENT_THRESHOLD:
        return float("nan")
    return value


def open_scope(ip_address, timeout_ms=15000):
    rm = pyvisa.ResourceManager("@py")
    inst = rm.open_resource(_resource_string(ip_address))
    inst.timeout = timeout_ms
    inst.read_termination = "\n"
    inst.write_termination = "\n"
    return rm, inst


def get_preamble(inst):
    fields = inst.query(":WAVeform:PREamble?").strip().split(",")
    return {
        "xincrement": float(fields[4]),
        "xorigin": float(fields[5]),
    }


def capture_waveform(inst, source):
    """Returns (x_values, y_values) for the currently displayed trace on
    `source` (e.g. "CHANnel1", or "MATH" for the FFT result). For a normal
    channel, x is time in seconds and y is volts; for MATH set to FFT, x is
    frequency in Hz and y is in whatever :MATH:FFT:UNIT is set to (dB or
    Vrms) - the same :WAVeform:PREamble?/:WAVeform:DATA? mechanism applies
    either way, just with different units.
    """
    inst.write(f":WAVeform:SOURce {source}")
    inst.write(":WAVeform:MODE NORM")  # just the ~1200 on-screen points
    inst.write(":WAVeform:FORMat ASCii")  # ASCII values are already real units
    inst.write(":WAVeform:STARt 1")
    inst.write(":WAVeform:STOP 1200")

    preamble = get_preamble(inst)
    raw = inst.query(":WAVeform:DATA?")
    if raw.startswith("#"):
        digit_count = int(raw[1])
        header_len = 2 + digit_count
        raw = raw[header_len:]
    values = [float(v) for v in raw.strip().split(",") if v.strip()]
    x_values = [preamble["xorigin"] + i * preamble["xincrement"] for i in range(len(values))]
    return x_values, values


def _get_raw_preamble_fields(inst):
    """Like get_preamble(), but also pulls the Y-axis fields needed to
    convert RAW/BYTE waveform data (raw ADC codes, not real units) into
    volts - the ASCII format used by capture_waveform() returns
    already-scaled values, so it never needed these.
    """
    fields = inst.query(":WAVeform:PREamble?").strip().split(",")
    return {
        "xincrement": float(fields[4]),
        "xorigin": float(fields[5]),
        "yincrement": float(fields[7]),
        "yorigin": float(fields[8]),
        "yreference": float(fields[9]),
    }


def capture_raw_waveform(inst, channel, num_points):
    """Reads up to `num_points` samples of `channel`'s full internal
    acquisition memory (not just the ~1200 on-screen points capture_
    waveform() reads) and returns (times, volts) as numpy arrays. The
    scope must already be STOPped - RAW mode only exposes more than the
    on-screen buffer while stopped.

    A single :WAVeform:DATA? query can't return the whole thing at once,
    so this reads it in chunks of _RAW_READ_CHUNK points at a time,
    advancing :WAVeform:STARt/:WAVeform:STOP each round - the same
    approach used by the well-tested pklaus/ds1054z open-source driver for
    this scope family. BYTE format returns raw 8-bit ADC codes rather than
    real units, converted to volts via the formula confirmed against
    Rigol's own official deep-memory data collection example:
        volts = (code - yreference - yorigin) * yincrement
    """
    inst.write(f":WAVeform:SOURce CHANnel{channel}")
    inst.write(":WAVeform:MODE RAW")
    inst.write(":WAVeform:FORMat BYTE")

    preamble = _get_raw_preamble_fields(inst)

    # Chunk-by-chunk logging - this loop previously had zero diagnostic
    # visibility, unlike everywhere else in this file. A real-hardware
    # failure here showed nothing but silence between the last setup print
    # and the eventual "resource not found" error from the *next* connect
    # attempt, with no way to tell which chunk (or whether the transfer
    # itself, vs. something after it) actually failed. Logging each chunk
    # as it completes - and exactly which one failed, if any - closes that
    # gap for next time.
    total_chunks = math.ceil(num_points / _RAW_READ_CHUNK)
    raw_bytes = bytearray()
    pos = 1
    chunk_num = 0
    while len(raw_bytes) < num_points:
        chunk_num += 1
        stop = min(num_points, pos + _RAW_READ_CHUNK - 1)
        try:
            inst.write(f":WAVeform:STARt {pos}")
            inst.write(f":WAVeform:STOP {stop}")
            inst.write(":WAVeform:DATA?")
            chunk_data = _strip_tmc_header(inst.read_raw())
        except pyvisa.errors.VisaIOError as exc:
            print(f"[Long capture read] chunk {chunk_num}/{total_chunks} "
                  f"(points {pos}-{stop}) FAILED: {exc}")
            raise
        print(f"[Long capture read] chunk {chunk_num}/{total_chunks} "
              f"(points {pos}-{stop}) OK, {len(chunk_data)} bytes")
        raw_bytes += chunk_data
        pos = stop + 1

    codes = np.frombuffer(bytes(raw_bytes[:num_points]), dtype=np.uint8).astype(np.float64)
    volts = (codes - preamble["yreference"] - preamble["yorigin"]) * preamble["yincrement"]
    times = preamble["xorigin"] + np.arange(len(volts)) * preamble["xincrement"]
    return times, volts


def compute_fft(times, volts):
    """Computes a full-resolution FFT of a raw time-domain trace using
    numpy directly, rather than the scope's own on-screen MATH FFT - this
    is what actually benefits from a long capture's much finer frequency
    resolution, since the scope's own FFT readout is tied to whatever's on
    the current display/timebase either way. Uses a Hanning window (same
    choice as the scope's own FFT pass, for a consistent look) with
    coherent-gain correction so the result still reads in true volts.

    Returns (freqs_hz, magnitude_v, magnitude_db) - magnitude_v is the
    single-sided linear amplitude spectrum in volts, magnitude_db is
    20*log10(magnitude_v) in dBV (0dB = 1V amplitude). Both are saved so
    either can be plotted without recomputing.
    """
    n = len(volts)
    dt = times[1] - times[0]
    window = np.hanning(n)
    coherent_gain = window.mean()
    windowed = (volts - volts.mean()) * window  # remove DC before windowing

    spectrum = np.fft.rfft(windowed) / n / coherent_gain
    freqs = np.fft.rfftfreq(n, d=dt)

    magnitude_v = 2 * np.abs(spectrum)  # single-sided amplitude
    magnitude_v[0] /= 2  # DC bin isn't doubled like the rest

    with np.errstate(divide="ignore"):
        magnitude_db = 20 * np.log10(np.maximum(magnitude_v, 1e-12))

    return freqs, magnitude_v, magnitude_db


def capture_screenshot(inst):
    """Returns the raw PNG bytes of the current screen."""
    inst.write(":DISPlay:DATA? ON,OFF,PNG")
    raw = inst.read_raw()
    return _strip_tmc_header(raw)


def _drain_scope_errors(inst, label):
    """Reads and prints any errors sitting in the scope's SCPI error queue,
    tagged with `label` so it's obvious which stage of the sequence they
    came from. A rejected command (e.g. an out-of-range parameter) doesn't
    raise anything on the Python/VISA side - the write() call returns
    normally, but the scope silently queues an error and shows something
    like "Invalid Input!" on its own screen. This is how that gets
    surfaced instead of guessed at.

    This is a diagnostic only - it must never be able to take down the
    capture it's checking. Real-hardware testing found the DC pass's
    :SYSTem:ERRor? query occasionally timing out outright, which (before
    this try/except) raised a VisaIOError that run_capture()'s retry
    wrapper caught, restarting the *entire* AC/FFT/DC sequence from
    scratch - three timeouts in a row looked like it "got stuck in a
    loop", producing three dead folders that each only got as far as
    AC+FFT. A timeout here now just gets logged and skipped.
    """
    for _ in range(20):
        try:
            entry = inst.query(":SYSTem:ERRor?").strip()
        except pyvisa.errors.VisaIOError as exc:
            print(f"[{label}] could not read scope error queue ({exc}) - skipping this check")
            return
        if entry.startswith("0,"):
            return
        print(f"[{label}] scope error: {entry}")


def measure_dc_level(inst, channel):
    """Average (DC) voltage on `channel`, or NaN if the scope reports an
    invalid measurement.
    """
    inst.write(f":MEASure:ITEM VAVG,CHANnel{channel}")
    return _parse_measurement(inst.query(f":MEASure:ITEM? VAVG,CHANnel{channel}"))


# The DS1000Z's max allowed :OFFSet magnitude depends on the CURRENT
# :SCALe: only +-2V below 500mV/div, but +-100V from 500mV/div up (confirmed
# against real hardware - a requested -3.3V offset at a 0.33V/div scale
# came back clamped to only -2.0V). Every rail we care about (3.3V+) needs
# more than 2V of offset to center, so the DC scale must never be allowed
# to drop below 500mV/div, regardless of how tightly zoomed-in that would
# otherwise be for a small rail.
MIN_DC_SCALE_FOR_OFFSET_RANGE = 0.5


def choose_dc_scale(dc_level, target_divisions=6, margin_fraction=0.3,
                     min_scale=MIN_DC_SCALE_FOR_OFFSET_RANGE, max_scale=MAX_CHANNEL_SCALE):
    """Volts/div that keeps a DC level of `dc_level` comfortably framed once
    centered via offset, with margin_fraction extra headroom above/below
    (e.g. 0.3 = the display comfortably covers +-30% around the level, in
    case the actual output is off from nominal or has some ripple).
    """
    span = abs(dc_level) * 2 * margin_fraction
    if span <= 0:
        return max_scale
    return min(max(span / target_divisions, min_scale), max_scale)


def _save_npz(run_folder, filename, arrays):
    """Saves any number of named arrays into one compressed .npz file - the
    Python-friendly replacement for the old per-run CSVs (a PI's
    suggestion, since 1M+ point traces are unwieldy as text). Load it back
    with:
        import numpy as np
        data = np.load("..._AC.npz")
        times, volts = data["time_s"], data["CH1_volts"]
    (whatever array names were passed in `arrays` here) - each file is
    self-describing without needing a separate header row the way the
    CSVs did.
    """
    path = os.path.join(run_folder, filename)
    np.savez_compressed(path, **{k: np.asarray(v) for k, v in arrays.items()})
    return path


def _save_png(run_folder, filename, png_bytes):
    path = os.path.join(run_folder, filename)
    with open(path, "wb") as f:
        f.write(png_bytes)
    return path


def save_long_capture_plot(output_folder, file_prefix, times, volts, freqs, magnitude_db):
    """Saves a quick-look PNG (time-domain trace + FFT spectrum, stacked)
    next to the long capture's .npz files. Unlike the AC/FFT/DC passes,
    there's no on-scope screenshot for this data (nothing meaningful to
    show on the scope's own screen for a record this size), so this is
    the only visual reference for a long capture run - matplotlib is
    imported lazily here (not at the top of the file) so the routine
    AC/FFT/DC-only path never pays its import cost when a long capture
    isn't actually being done.
    """
    import matplotlib
    matplotlib.use("Agg")  # headless/file-only backend - no GUI, safe from any thread
    import matplotlib.pyplot as plt

    fig, (ax1, ax2) = plt.subplots(2, 1, figsize=(11, 7))

    ax1.plot(times * 1e3, volts * 1e3, linewidth=0.5)
    ax1.set_xlabel("Time (ms)")
    ax1.set_ylabel("Voltage (mV)")
    ax1.set_title(f"Long AC-coupled trace ({len(times):,} points)")
    ax1.grid(True, alpha=0.3)

    ax2.plot(freqs / 1e6, magnitude_db, linewidth=0.5)
    ax2.set_xlabel("Frequency (MHz)")
    ax2.set_ylabel("Magnitude (dBV)")
    ax2.set_title("Full-resolution FFT")
    ax2.grid(True, alpha=0.3)

    fig.tight_layout()
    path = os.path.join(output_folder, f"{file_prefix}_LONG.png")
    fig.savefig(path, dpi=110)
    plt.close(fig)
    return path


def run_capture(ip_address, expected_dc_voltage=None, include_long_capture=False,
                 progress_callback=None, max_attempts=3, retry_delay_s=5.0):
    """Connects to the scope, grabs an AC-coupled snapshot, an FFT of that
    ripple, and a DC-coupled snapshot into their own timestamped folder
    under Snapshots/, and returns (run_folder, measured_dc_level) -
    measured_dc_level is NaN if that measurement was invalid.

    expected_dc_voltage, if given, is the nominal voltage you expect this
    rail to be (e.g. 12.0 for a 12V rail). It's used to set a safe starting
    scale *before* switching to DC coupling and measuring - without it, the
    scope would still be on whatever tiny scale was tuned for AC ripple
    viewing, and a real DC level would clip off-screen immediately, making
    the very first measurement inaccurate (a measurement taken while
    clipped doesn't reflect the true voltage). If not given, a generously
    wide default scale is used instead so nothing clips, at the cost of a
    less-precise first measurement (still corrected in a second pass).

    include_long_capture, if True, also runs the long-trace capture
    (LONG_TRACE_POINTS raw samples + a full-resolution Python FFT) as part
    of this same run, reusing the same connection - saved in a
    longcapture_<timestamp> subfolder alongside the AC/FFT/DC files rather
    than its own separate top-level folder, so it's obvious it belongs to
    this particular snapshot. For a long capture on its own, without the
    rest of the sequence, use run_long_capture() instead.

    progress_callback(stage, status), if given, is called with
    stage in ("ac", "fft", "dc") - plus "long" if include_long_capture is
    True - and status in ("in_progress", "done") - lets a GUI show
    per-stage progress without this function knowing about Tkinter.

    Retries the whole capture (fresh connection each time) up to
    max_attempts times if it fails with a VISA I/O error - this scope's
    LAN/VXI-11 connection can occasionally get into a stale state after
    several connections in quick succession (same issue seen with the
    filter sweep tool), and a fresh reconnect after a pause usually clears
    it. The default pause (retry_delay_s) is longer than it used to be -
    real-hardware testing with a bundled long capture saw the *next*
    reconnect attempt fail outright with VI_ERROR_RSRC_NFOUND (the scope
    not found at all, not just a slow response) after a capture that kept
    the connection open much longer and moved far more data than the
    routine passes - suggesting the LAN interface needs more than a
    couple seconds to fully release a heavier connection before it's
    ready to accept a new one.
    """
    progress_callback = progress_callback or (lambda stage, status: None)

    last_error = None
    for attempt in range(1, max_attempts + 1):
        try:
            return _run_capture_once(ip_address, expected_dc_voltage, include_long_capture,
                                      progress_callback)
        except pyvisa.errors.VisaIOError as exc:
            last_error = exc
            if attempt < max_attempts:
                time.sleep(retry_delay_s)
    raise last_error
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

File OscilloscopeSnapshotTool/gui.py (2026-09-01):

"""Tkinter GUI for the power supply snapshot tool - wraps capture.py so you
don't need to type a command in a terminal every time you want a snapshot.
"""

import os
import queue
import threading

import tkinter as tk
from tkinter import ttk, messagebox

import pyvisa

import capture


class SnapshotApp(tk.Tk):
    def __init__(self):
        super().__init__()
        self.title("Power Supply Snapshot Tool")
        self.geometry("560x420")
        self.resizable(False, False)

        self.result_queue = queue.Queue()
        self.worker_thread = None
        self._animation_jobs = {"ac": None, "fft": None, "dc": None, "long": None}

        self._build_scroll_container()
        self._build_widgets()
        self._poll_queue()

    # -- scrolling ---------------------------------------------------------

    def _build_scroll_container(self):
        """Wraps everything in a Canvas + Scrollbar, with mouse-wheel
        scrolling - the window is a fixed size (resizable(False, False)
        above), but content can still end up taller than that (larger
        system font/DPI scaling, or just more rows added over time), which
        would otherwise clip the bottom of the window with no way to
        reach it. Widgets get built into self.content (a plain ttk.Frame)
        instead of directly into `self` from here on.
        """
        container = ttk.Frame(self)
        container.pack(fill="both", expand=True)

        self._canvas = tk.Canvas(container, highlightthickness=0)
        scrollbar = ttk.Scrollbar(container, orient="vertical", command=self._canvas.yview)
        self._canvas.configure(yscrollcommand=scrollbar.set)
        self._canvas.pack(side="left", fill="both", expand=True)
        scrollbar.pack(side="right", fill="y")

        self.content = ttk.Frame(self._canvas)
        self._content_window = self._canvas.create_window((0, 0), window=self.content, anchor="nw")

        self.content.bind("<Configure>", self._on_content_configure)
        self._canvas.bind("<Configure>", self._on_canvas_configure)

        # Only scroll with the wheel while the pointer is actually over
        # this window's canvas, rather than binding globally for the
        # whole Tk application the entire time.
        self._canvas.bind("<Enter>", lambda e: self._canvas.bind_all("<MouseWheel>", self._on_mousewheel))
        self._canvas.bind("<Leave>", lambda e: self._canvas.unbind_all("<MouseWheel>"))

    def _on_content_configure(self, _event):
        self._canvas.configure(scrollregion=self._canvas.bbox("all"))

    def _on_canvas_configure(self, event):
        # Keep the inner content frame exactly as wide as the visible
        # canvas, so widgets packed with fill="x" still stretch the same
        # way they would have directly inside the window.
        self._canvas.itemconfigure(self._content_window, width=event.width)

    def _on_mousewheel(self, event):
        # Windows delivers <MouseWheel> with event.delta in multiples of
        # 120 per notch.
        self._canvas.yview_scroll(int(-1 * (event.delta / 120)), "units")

    # -- UI construction -----------------------------------------------

    def _build_widgets(self):
        conn_frame = ttk.LabelFrame(self.content, text="Oscilloscope connection (LAN)")
        conn_frame.pack(fill="x", padx=8, pady=6)

        ttk.Label(conn_frame, text="Scope IP:").grid(row=0, column=0, sticky="w", padx=4, pady=6)
        self.ip_var = tk.StringVar(value="192.168.1.50")
        ttk.Entry(conn_frame, textvariable=self.ip_var, width=18).grid(row=0, column=1, padx=4, pady=6)

        self.test_button = ttk.Button(conn_frame, text="Test Connection", command=self._on_test_connection)
        self.test_button.grid(row=0, column=2, padx=8, pady=6)

        self.conn_status_var = tk.StringVar(value="Not tested")
        ttk.Label(conn_frame, textvariable=self.conn_status_var).grid(row=0, column=3, padx=4, pady=6, sticky="w")

        ttk.Label(conn_frame, text="Expected DC voltage (V):").grid(row=1, column=0, sticky="w", padx=4, pady=6)
        self.expected_dc_var = tk.StringVar(value="")
        ttk.Entry(conn_frame, textvariable=self.expected_dc_var, width=10).grid(
            row=1, column=1, padx=4, pady=6, sticky="w"
        )
        ttk.Label(conn_frame, text="(optional - helps set a safe scale and flags if it's off)").grid(
            row=1, column=2, columnspan=2, padx=4, pady=6, sticky="w"
        )

        self.include_long_var = tk.BooleanVar(value=False)
        ttk.Checkbutton(
            conn_frame,
            text=f"Also do a long capture ({capture.LONG_TRACE_POINTS:,} points + FFT, "
            "saved in a subfolder - takes longer)",
            variable=self.include_long_var,
        ).grid(row=2, column=0, columnspan=4, sticky="w", padx=4, pady=(0, 6))

        progress_frame = ttk.LabelFrame(self.content, text="Snapshot progress")
        progress_frame.pack(fill="x", padx=8, pady=6)

        ttk.Label(progress_frame, text="AC (ripple/noise):").grid(row=0, column=0, sticky="w", padx=4, pady=8)
        self.ac_progress = ttk.Progressbar(progress_frame, mode="determinate", length=260, maximum=100)
        self.ac_progress.grid(row=0, column=1, padx=4, pady=8)
        self.ac_status_var = tk.StringVar(value="Idle")
        ttk.Label(progress_frame, textvariable=self.ac_status_var, width=10).grid(row=0, column=2, padx=4)

        ttk.Label(progress_frame, text="FFT (spectrum):").grid(row=1, column=0, sticky="w", padx=4, pady=8)
        self.fft_progress = ttk.Progressbar(progress_frame, mode="determinate", length=260, maximum=100)
        self.fft_progress.grid(row=1, column=1, padx=4, pady=8)
        self.fft_status_var = tk.StringVar(value="Idle")
        ttk.Label(progress_frame, textvariable=self.fft_status_var, width=10).grid(row=1, column=2, padx=4)

        ttk.Label(progress_frame, text="DC (output level):").grid(row=2, column=0, sticky="w", padx=4, pady=8)
        self.dc_progress = ttk.Progressbar(progress_frame, mode="determinate", length=260, maximum=100)
        self.dc_progress.grid(row=2, column=1, padx=4, pady=8)
        self.dc_status_var = tk.StringVar(value="Idle")
        ttk.Label(progress_frame, textvariable=self.dc_status_var, width=10).grid(row=2, column=2, padx=4)

        ttk.Label(progress_frame, text="Long capture (optional):").grid(
            row=3, column=0, sticky="w", padx=4, pady=8
        )
        self.long_progress = ttk.Progressbar(progress_frame, mode="determinate", length=260, maximum=100)
        self.long_progress.grid(row=3, column=1, padx=4, pady=8)
        self.long_status_var = tk.StringVar(value="Idle")
        ttk.Label(progress_frame, textvariable=self.long_status_var, width=10).grid(row=3, column=2, padx=4)

        control_frame = ttk.Frame(self.content)
        control_frame.pack(fill="x", padx=8, pady=10)
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
